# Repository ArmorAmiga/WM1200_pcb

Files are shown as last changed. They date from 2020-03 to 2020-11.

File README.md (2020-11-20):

# ArmorAmiga "Wishmaster" PCB repository

This is an early prototype of ARM-based A1200 turbo board.

PCB design was created in [KiCAD EDA](https://kicad.org/).

It consists of the following parts:
 * Wishmaster carrier board
 * Alinx AC7010/AC7020 Xilinx Zynq development board (available on Aliexpress, for example: https://aliexpress.ru/item/4000585279066.html). Most likely, you will also need a Xilinx JTAG cable to work with it as a developer.

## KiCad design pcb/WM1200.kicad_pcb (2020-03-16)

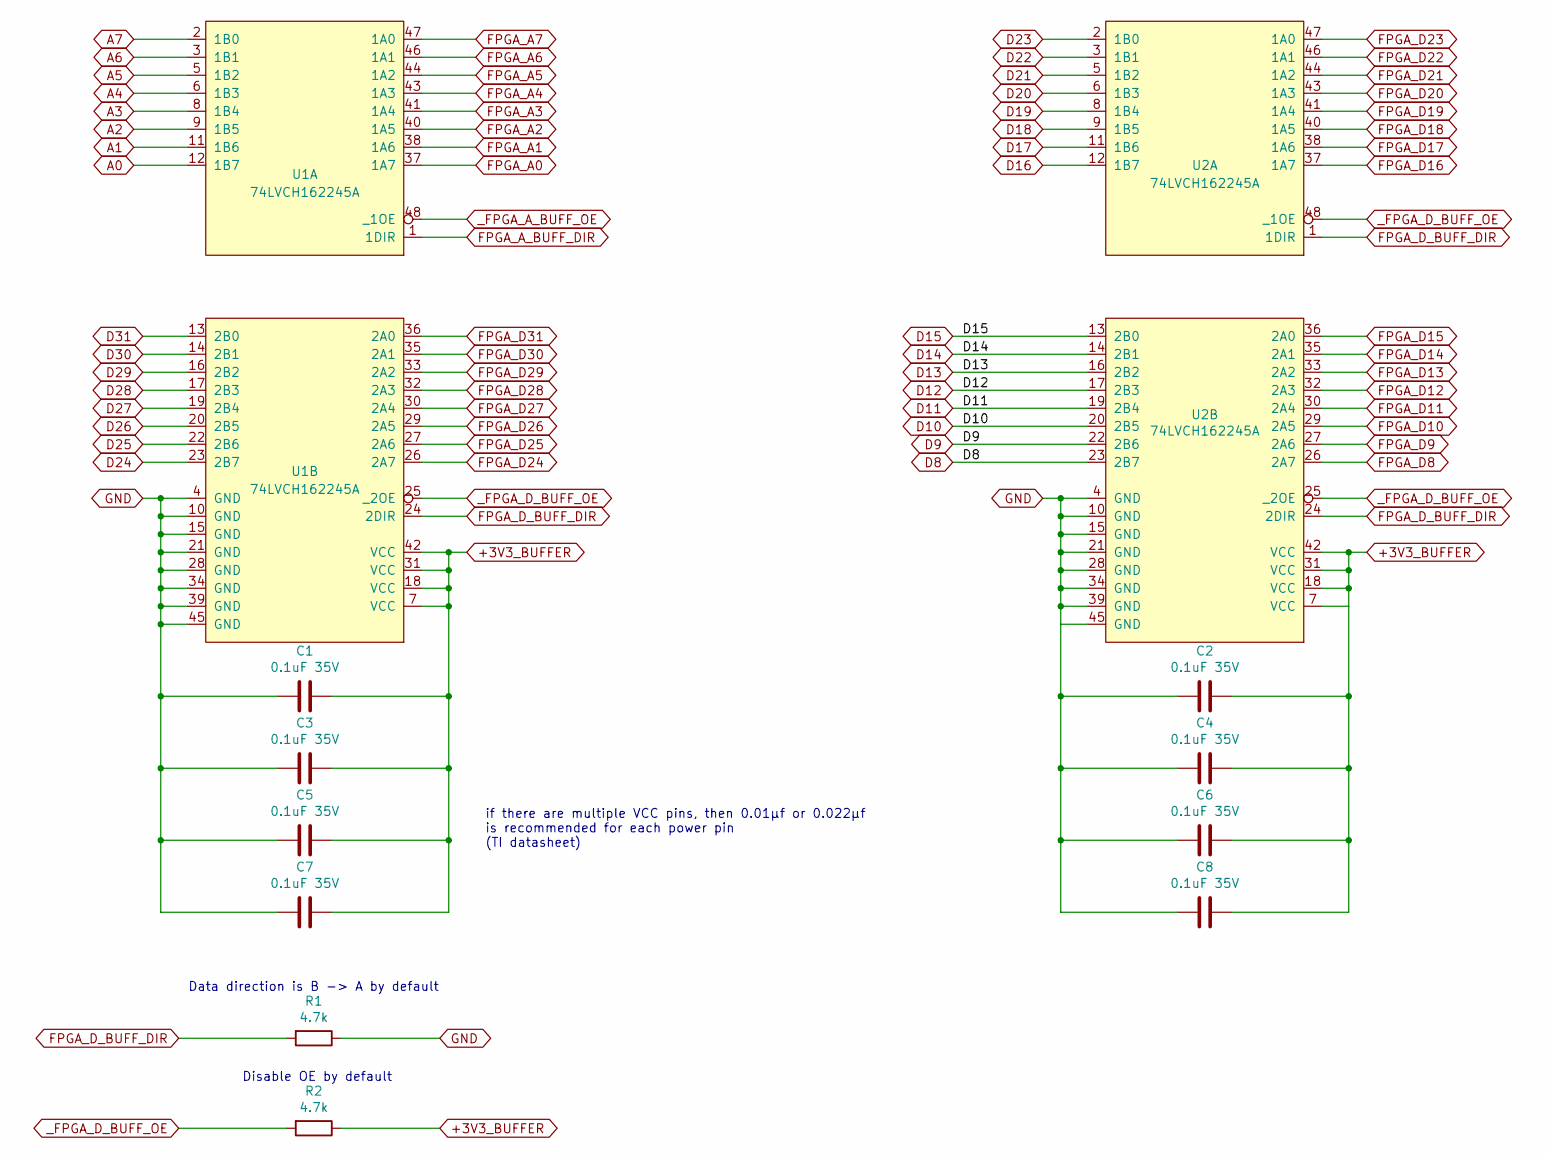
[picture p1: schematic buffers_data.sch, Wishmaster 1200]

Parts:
C1, C2, C3, C4, C5, C6, C7, C8: 0.1uF 35V; C_0402_1005Metric
R1, R2: 4.7k; R_0603_1608Metric_Pad1.05x0.95mm_HandSolder
U1, U2: 74LVCH162245A; TSSOP-48_6.1x12.5mm_P0.5mm

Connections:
+3V3_BUFFER: C1.2, C2.2, C3.2, C4.2, C5.2, C6.2, C7.2, C8.2, R2.1, U1.7 (VCC), U1.18 (VCC), U1.31 (VCC), U1.42 (VCC), U2.7 (VCC), U2.18 (VCC), U2.31 (VCC), U2.42 (VCC); also elsewhere on the board
A0: U1.12 (1B7); also elsewhere on the board
A1: U1.11 (1B6); also elsewhere on the board
A2: U1.9 (1B5); also elsewhere on the board
A3: U1.8 (1B4); also elsewhere on the board
A4: U1.6 (1B3); also elsewhere on the board
A5: U1.5 (1B2); also elsewhere on the board
A6: U1.3 (1B1); also elsewhere on the board
A7: U1.2 (1B0); also elsewhere on the board
D8: U2.23 (2B7); also elsewhere on the board
D9: U2.22 (2B6); also elsewhere on the board
D10: U2.20 (2B5); also elsewhere on the board
D11: U2.19 (2B4); also elsewhere on the board
D12: U2.17 (2B3); also elsewhere on the board
D13: U2.16 (2B2); also elsewhere on the board
D14: U2.14 (2B1); also elsewhere on the board
D15: U2.13 (2B0); also elsewhere on the board
D16: U2.12 (1B7); also elsewhere on the board
D17: U2.11 (1B6); also elsewhere on the board
D18: U2.9 (1B5); also elsewhere on the board
D19: U2.8 (1B4); also elsewhere on the board
D20: U2.6 (1B3); also elsewhere on the board
D21: U2.5 (1B2); also elsewhere on the board
D22: U2.3 (1B1); also elsewhere on the board
D23: U2.2 (1B0); also elsewhere on the board
D24: U1.23 (2B7); also elsewhere on the board
D25: U1.22 (2B6); also elsewhere on the board
D26: U1.20 (2B5); also elsewhere on the board
D27: U1.19 (2B4); also elsewhere on the board
D28: U1.17 (2B3); also elsewhere on the board
D29: U1.16 (2B2); also elsewhere on the board
D30: U1.14 (2B1); also elsewhere on the board
D31: U1.13 (2B0); also elsewhere on the board
FPGA_A0: U1.37 (1A7); also elsewhere on the board
FPGA_A1: U1.38 (1A6); also elsewhere on the board
FPGA_A2: U1.40 (1A5); also elsewhere on the board
FPGA_A3: U1.41 (1A4); also elsewhere on the board
FPGA_A4: U1.43 (1A3); also elsewhere on the board
FPGA_A5: U1.44 (1A2); also elsewhere on the board
FPGA_A6: U1.46 (1A1); also elsewhere on the board
FPGA_A7: U1.47 (1A0); also elsewhere on the board
FPGA_A_BUFF_DIR: U1.1 (1DIR); also elsewhere on the board
FPGA_D8: U2.26 (2A7); also elsewhere on the board
FPGA_D9: U2.27 (2A6); also elsewhere on the board
FPGA_D10: U2.29 (2A5); also elsewhere on the board
FPGA_D11: U2.30 (2A4); also elsewhere on the board
FPGA_D12: U2.32 (2A3); also elsewhere on the board
FPGA_D13: U2.33 (2A2); also elsewhere on the board
FPGA_D14: U2.35 (2A1); also elsewhere on the board
FPGA_D15: U2.36 (2A0); also elsewhere on the board
FPGA_D16: U2.37 (1A7); also elsewhere on the board
FPGA_D17: U2.38 (1A6); also elsewhere on the board
FPGA_D18: U2.40 (1A5); also elsewhere on the board
FPGA_D19: U2.41 (1A4); also elsewhere on the board
FPGA_D20: U2.43 (1A3); also elsewhere on the board
FPGA_D21: U2.44 (1A2); also elsewhere on the board
FPGA_D22: U2.46 (1A1); also elsewhere on the board
FPGA_D23: U2.47 (1A0); also elsewhere on the board
FPGA_D24: U1.26 (2A7); also elsewhere on the board
FPGA_D25: U1.27 (2A6); also elsewhere on the board
FPGA_D26: U1.29 (2A5); also elsewhere on the board
FPGA_D27: U1.30 (2A4); also elsewhere on the board
FPGA_D28: U1.32 (2A3); also elsewhere on the board
FPGA_D29: U1.33 (2A2); also elsewhere on the board
FPGA_D30: U1.35 (2A1); also elsewhere on the board
FPGA_D31: U1.36 (2A0); also elsewhere on the board
FPGA_D_BUFF_DIR: R1.2, U1.24 (2DIR), U2.1 (1DIR), U2.24 (2DIR); also elsewhere on the board
GND: C1.1, C2.1, C3.1, C4.1, C5.1, C6.1, C7.1, C8.1, R1.1, U1.4 (GND), U1.10 (GND), U1.15 (GND), U1.21 (GND), U1.28 (GND), U1.34 (GND), U1.39 (GND), U1.45 (GND), U2.4 (GND), U2.10 (GND), U2.15 (GND), U2.21 (GND), U2.28 (GND), U2.34 (GND), U2.39 (GND), U2.45 (GND); also elsewhere on the board
_FPGA_A_BUFF_OE: U1.48 (_1OE); also elsewhere on the board
_FPGA_D_BUFF_OE: R2.2, U1.25 (_2OE), U2.25 (_2OE), U2.48 (_1OE); also elsewhere on the board

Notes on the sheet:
Disable OE by default
Data direction is B -> A by default
if there are multiple VCC pins, then 0.01μf or 0.022μf is recommended for each power pin (TI datasheet)

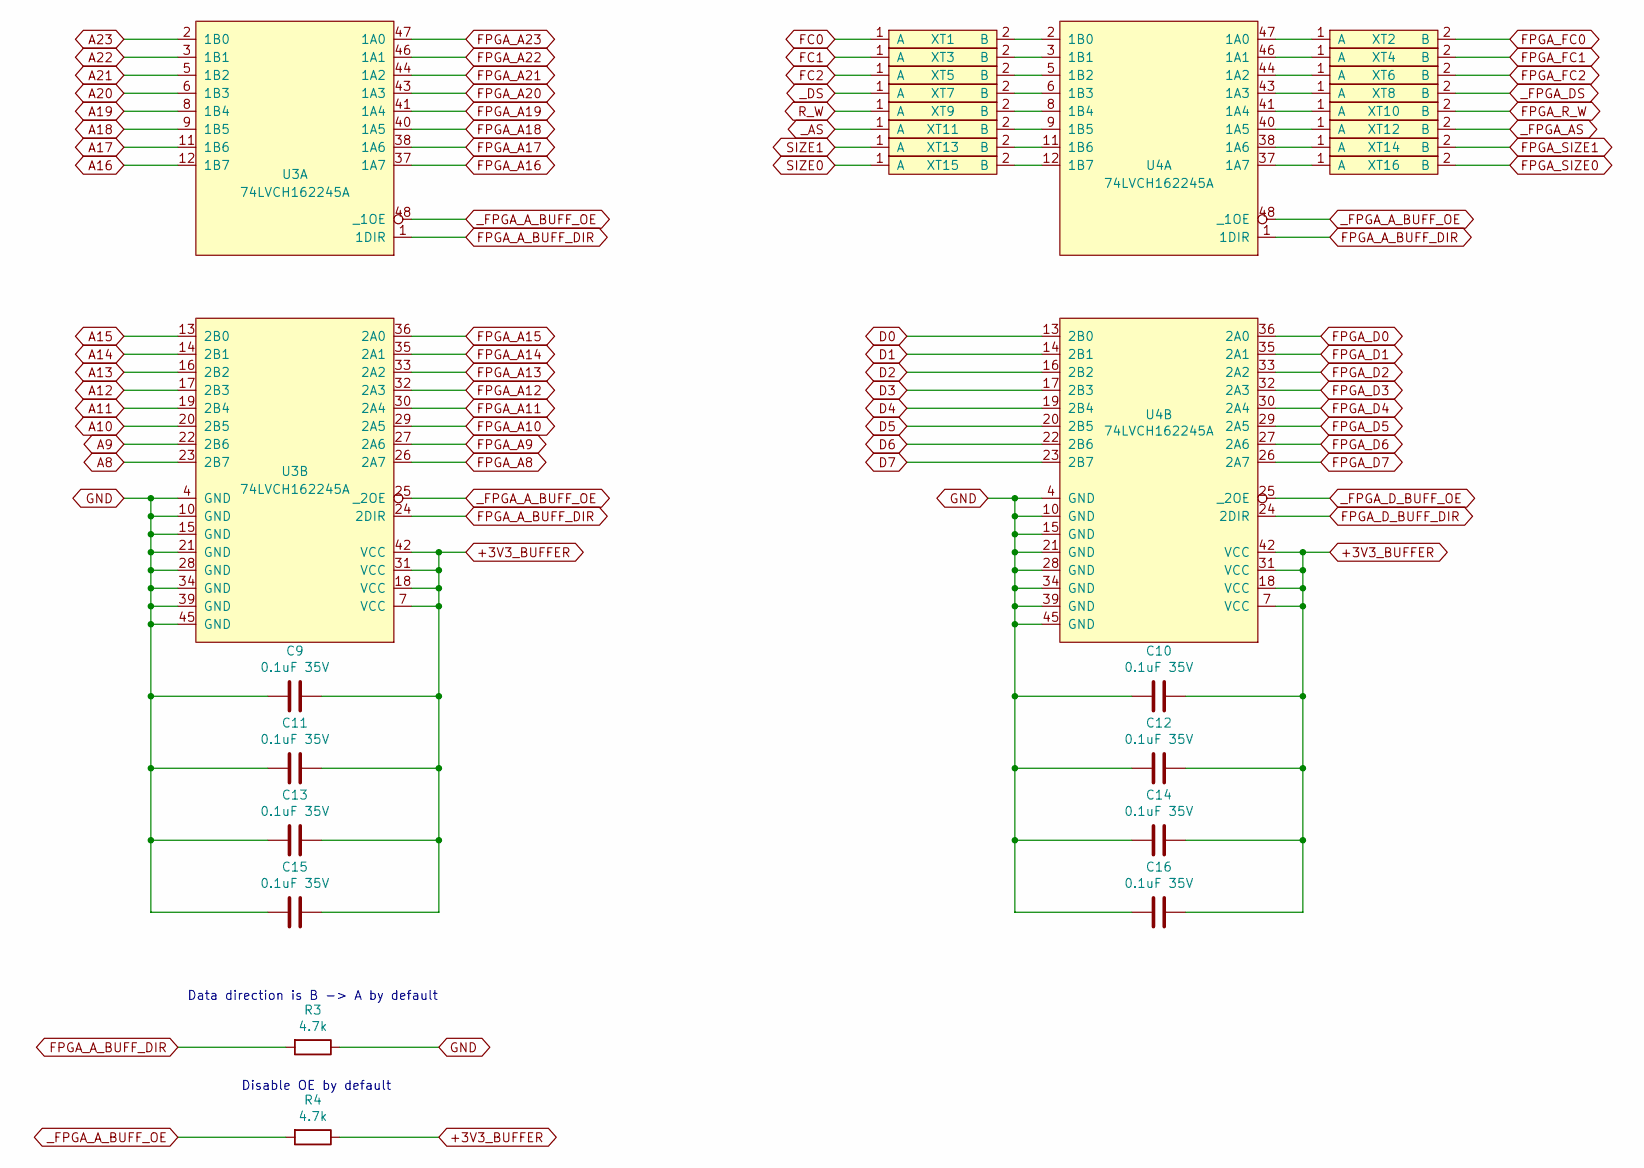
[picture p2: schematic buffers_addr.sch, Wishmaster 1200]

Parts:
C9, C10, C11, C12, C13, C14, C15, C16: 0.1uF 35V; C_0402_1005Metric
R3, R4: 4.7k; R_0603_1608Metric_Pad1.05x0.95mm_HandSolder
U3, U4: 74LVCH162245A; TSSOP-48_6.1x12.5mm_P0.5mm
XT1, XT2, XT3, XT4, XT5, XT6, XT7, XT8, XT9, XT10, XT11, XT12, XT13, XT14, XT15, XT16: testpoint_cutline

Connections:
+3V3_BUFFER: C9.2, C10.2, C11.2, C12.2, C13.2, C14.2, C15.2, C16.2, R4.1, U3.7 (VCC), U3.18 (VCC), U3.31 (VCC), U3.42 (VCC), U4.7 (VCC), U4.18 (VCC), U4.31 (VCC), U4.42 (VCC); also elsewhere on the board
A8: U3.23 (2B7); also elsewhere on the board
A9: U3.22 (2B6); also elsewhere on the board
A10: U3.20 (2B5); also elsewhere on the board
A11: U3.19 (2B4); also elsewhere on the board
A12: U3.17 (2B3); also elsewhere on the board
A13: U3.16 (2B2); also elsewhere on the board
A14: U3.14 (2B1); also elsewhere on the board
A15: U3.13 (2B0); also elsewhere on the board
A16: U3.12 (1B7); also elsewhere on the board
A17: U3.11 (1B6); also elsewhere on the board
A18: U3.9 (1B5); also elsewhere on the board
A19: U3.8 (1B4); also elsewhere on the board
A20: U3.6 (1B3); also elsewhere on the board
A21: U3.5 (1B2); also elsewhere on the board
A22: U3.3 (1B1); also elsewhere on the board
A23: U3.2 (1B0); also elsewhere on the board
D0: U4.13 (2B0); also elsewhere on the board
D1: U4.14 (2B1); also elsewhere on the board
D2: U4.16 (2B2); also elsewhere on the board
D3: U4.17 (2B3); also elsewhere on the board
D4: U4.19 (2B4); also elsewhere on the board
D5: U4.20 (2B5); also elsewhere on the board
D6: U4.22 (2B6); also elsewhere on the board
D7: U4.23 (2B7); also elsewhere on the board
FC0: XT1.1 (A); also elsewhere on the board
FC1: XT3.1 (A); also elsewhere on the board
FC2: XT5.1 (A); also elsewhere on the board
FPGA_A8: U3.26 (2A7); also elsewhere on the board
FPGA_A9: U3.27 (2A6); also elsewhere on the board
FPGA_A10: U3.29 (2A5); also elsewhere on the board
FPGA_A11: U3.30 (2A4); also elsewhere on the board
FPGA_A12: U3.32 (2A3); also elsewhere on the board
FPGA_A13: U3.33 (2A2); also elsewhere on the board
FPGA_A14: U3.35 (2A1); also elsewhere on the board
FPGA_A15: U3.36 (2A0); also elsewhere on the board
FPGA_A16: U3.37 (1A7); also elsewhere on the board
FPGA_A17: U3.38 (1A6); also elsewhere on the board
FPGA_A18: U3.40 (1A5); also elsewhere on the board
FPGA_A19: U3.41 (1A4); also elsewhere on the board
FPGA_A20: U3.43 (1A3); also elsewhere on the board
FPGA_A21: U3.44 (1A2); also elsewhere on the board
FPGA_A22: U3.46 (1A1); also elsewhere on the board
FPGA_A23: U3.47 (1A0); also elsewhere on the board
FPGA_A_BUFF_DIR: R3.2, U3.1 (1DIR), U3.24 (2DIR), U4.1 (1DIR); also elsewhere on the board
FPGA_D0: U4.36 (2A0); also elsewhere on the board
FPGA_D1: U4.35 (2A1); also elsewhere on the board
FPGA_D2: U4.33 (2A2); also elsewhere on the board
FPGA_D3: U4.32 (2A3); also elsewhere on the board
FPGA_D4: U4.30 (2A4); also elsewhere on the board
FPGA_D5: U4.29 (2A5); also elsewhere on the board
FPGA_D6: U4.27 (2A6); also elsewhere on the board
FPGA_D7: U4.26 (2A7); also elsewhere on the board
FPGA_D_BUFF_DIR: U4.24 (2DIR); also elsewhere on the board
FPGA_FC0: XT2.2 (B); also elsewhere on the board
FPGA_FC1: XT4.2 (B); also elsewhere on the board
FPGA_FC2: XT6.2 (B); also elsewhere on the board
FPGA_R_W: XT10.2 (B); also elsewhere on the board
FPGA_SIZE0: XT16.2 (B); also elsewhere on the board
FPGA_SIZE1: XT14.2 (B); also elsewhere on the board
GND: C9.1, C10.1, C11.1, C12.1, C13.1, C14.1, C15.1, C16.1, R3.1, U3.4 (GND), U3.10 (GND), U3.15 (GND), U3.21 (GND), U3.28 (GND), U3.34 (GND), U3.39 (GND), U3.45 (GND), U4.4 (GND), U4.10 (GND), U4.15 (GND), U4.21 (GND), U4.28 (GND), U4.34 (GND), U4.39 (GND), U4.45 (GND); also elsewhere on the board
unnamed: U4.2 (1B0), XT1.2 (B)
unnamed: U4.3 (1B1), XT3.2 (B)
unnamed: U4.5 (1B2), XT5.2 (B)
unnamed: U4.6 (1B3), XT7.2 (B)
unnamed: U4.8 (1B4), XT9.2 (B)
unnamed: U4.9 (1B5), XT11.2 (B)
unnamed: U4.11 (1B6), XT13.2 (B)
unnamed: U4.12 (1B7), XT15.2 (B)
unnamed: U4.37 (1A7), XT16.1 (A)
unnamed: U4.38 (1A6), XT14.1 (A)
unnamed: U4.40 (1A5), XT12.1 (A)
unnamed: U4.41 (1A4), XT10.1 (A)
unnamed: U4.43 (1A3), XT8.1 (A)
unnamed: U4.44 (1A2), XT6.1 (A)
unnamed: U4.46 (1A1), XT4.1 (A)
unnamed: U4.47 (1A0), XT2.1 (A)
R_W: XT9.1 (A); also elsewhere on the board
SIZE0: XT15.1 (A); also elsewhere on the board
SIZE1: XT13.1 (A); also elsewhere on the board
_AS: XT11.1 (A); also elsewhere on the board
_DS: XT7.1 (A); also elsewhere on the board
_FPGA_AS: XT12.2 (B); also elsewhere on the board
_FPGA_A_BUFF_OE: R4.2, U3.25 (_2OE), U3.48 (_1OE), U4.48 (_1OE); also elsewhere on the board
_FPGA_DS: XT8.2 (B); also elsewhere on the board
_FPGA_D_BUFF_OE: U4.25 (_2OE); also elsewhere on the board

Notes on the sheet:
Disable OE by default
Data direction is B -> A by default

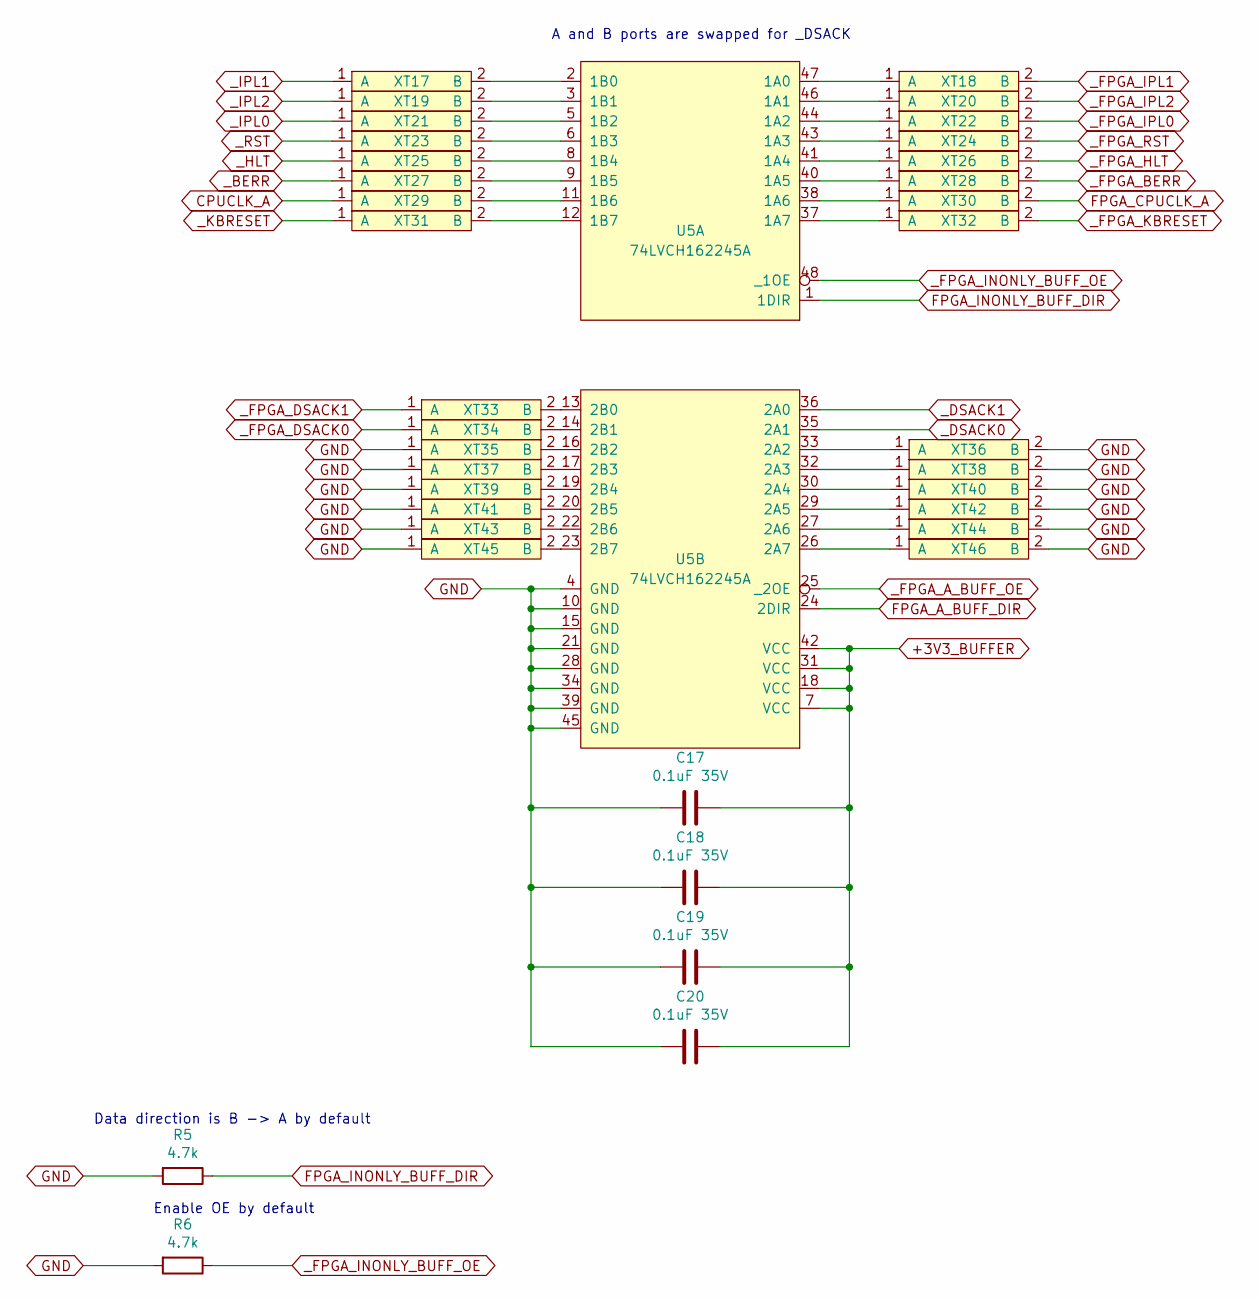
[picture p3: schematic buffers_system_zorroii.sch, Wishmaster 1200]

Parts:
C17, C18, C19, C20: 0.1uF 35V; C_0402_1005Metric
R5, R6: 4.7k; R_0603_1608Metric_Pad1.05x0.95mm_HandSolder
U5: 74LVCH162245A; TSSOP-48_6.1x12.5mm_P0.5mm
XT17, XT18, XT19, XT20, XT21, XT22, XT23, XT24, XT25, XT26, XT27, XT28, XT29, XT30, XT31, XT32, XT33, XT34, XT35, XT36, XT37, XT38, XT39, XT40, XT41, XT42, XT43, XT44, XT45, XT46: testpoint_cutline

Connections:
+3V3_BUFFER: C17.2, C18.2, C19.2, C20.2, U5.7 (VCC), U5.18 (VCC), U5.31 (VCC), U5.42 (VCC); also elsewhere on the board
CPUCLK_A: XT29.1 (A); also elsewhere on the board
FPGA_A_BUFF_DIR: U5.24 (2DIR); also elsewhere on the board
FPGA_CPUCLK_A: XT30.2 (B); also elsewhere on the board
FPGA_INONLY_BUFF_DIR: R5.1, U5.1 (1DIR)
GND: C17.1, C18.1, C19.1, C20.1, R5.2, R6.2, U5.4 (GND), U5.10 (GND), U5.15 (GND), U5.21 (GND), U5.28 (GND), U5.34 (GND), U5.39 (GND), U5.45 (GND), XT35.1 (A), XT36.2 (B), XT37.1 (A), XT38.2 (B), XT39.1 (A), XT40.2 (B), XT41.1 (A), XT42.2 (B), XT43.1 (A), XT44.2 (B), XT45.1 (A), XT46.2 (B); also elsewhere on the board
unnamed: U5.2 (1B0), XT17.2 (B)
unnamed: U5.3 (1B1), XT19.2 (B)
unnamed: U5.5 (1B2), XT21.2 (B)
unnamed: U5.6 (1B3), XT23.2 (B)
unnamed: U5.8 (1B4), XT25.2 (B)
unnamed: U5.9 (1B5), XT27.2 (B)
unnamed: U5.11 (1B6), XT29.2 (B)
unnamed: U5.12 (1B7), XT31.2 (B)
unnamed: U5.13 (2B0), XT33.2 (B)
unnamed: U5.14 (2B1), XT34.2 (B)
unnamed: U5.16 (2B2), XT35.2 (B)
unnamed: U5.17 (2B3), XT37.2 (B)
unnamed: U5.19 (2B4), XT39.2 (B)
unnamed: U5.20 (2B5), XT41.2 (B)
unnamed: U5.22 (2B6), XT43.2 (B)
unnamed: U5.23 (2B7), XT45.2 (B)
unnamed: U5.26 (2A7), XT46.1 (A)
unnamed: U5.27 (2A6), XT44.1 (A)
unnamed: U5.29 (2A5), XT42.1 (A)
unnamed: U5.30 (2A4), XT40.1 (A)
unnamed: U5.32 (2A3), XT38.1 (A)
unnamed: U5.33 (2A2), XT36.1 (A)
unnamed: U5.37 (1A7), XT32.1 (A)
unnamed: U5.38 (1A6), XT30.1 (A)
unnamed: U5.40 (1A5), XT28.1 (A)
unnamed: U5.41 (1A4), XT26.1 (A)
unnamed: U5.43 (1A3), XT24.1 (A)
unnamed: U5.44 (1A2), XT22.1 (A)
unnamed: U5.46 (1A1), XT20.1 (A)
unnamed: U5.47 (1A0), XT18.1 (A)
_BERR: XT27.1 (A); also elsewhere on the board
_DSACK0: U5.35 (2A1); also elsewhere on the board
_DSACK1: U5.36 (2A0); also elsewhere on the board
_FPGA_A_BUFF_OE: U5.25 (_2OE); also elsewhere on the board
_FPGA_BERR: XT28.2 (B); also elsewhere on the board
_FPGA_DSACK0: XT34.1 (A); also elsewhere on the board
_FPGA_DSACK1: XT33.1 (A); also elsewhere on the board
_FPGA_HLT: XT26.2 (B); also elsewhere on the board
_FPGA_INONLY_BUFF_OE: R6.1, U5.48 (_1OE)
_FPGA_IPL0: XT22.2 (B); also elsewhere on the board
_FPGA_IPL1: XT18.2 (B); also elsewhere on the board
_FPGA_IPL2: XT20.2 (B); also elsewhere on the board
_FPGA_KBRESET: XT32.2 (B); also elsewhere on the board
_FPGA_RST: XT24.2 (B); also elsewhere on the board
_HLT: XT25.1 (A); also elsewhere on the board
_IPL0: XT21.1 (A); also elsewhere on the board
_IPL1: XT17.1 (A); also elsewhere on the board
_IPL2: XT19.1 (A); also elsewhere on the board
_KBRESET: XT31.1 (A); also elsewhere on the board
_RST: XT23.1 (A); also elsewhere on the board

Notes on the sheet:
Enable OE by default
Data direction is B -> A by default
A and B ports are swapped for _DSACK

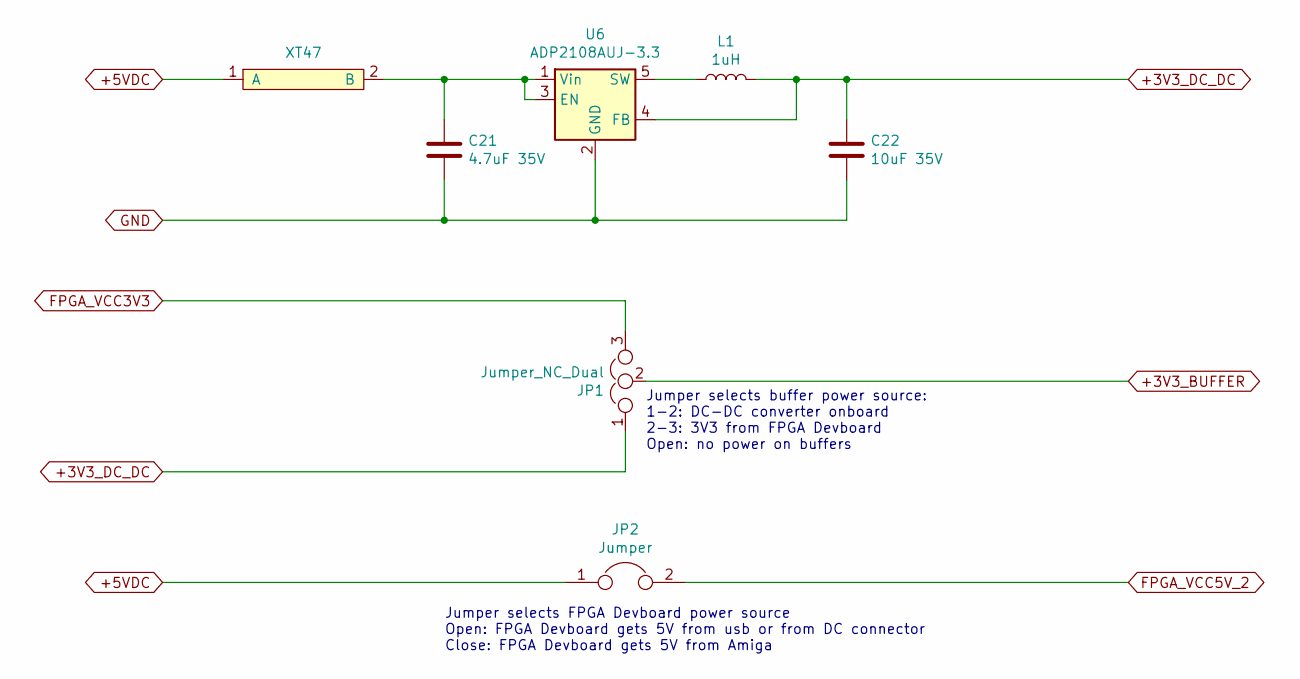
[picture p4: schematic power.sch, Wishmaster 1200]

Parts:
C21: 4.7uF 35V; C_1210_3225Metric_Pad1.42x2.65mm_HandSolder
C22: 10uF 35V; C_1210_3225Metric_Pad1.42x2.65mm_HandSolder
JP1: Jumper_NC_Dual; PinHeader_1x03_P2.54mm_Vertical
JP2: Jumper; PinHeader_1x02_P2.54mm_Vertical
L1: 1uH; L_0603_1608Metric_Pad1.05x0.95mm_HandSolder
U6: ADP2108AUJ-3.3; TSOT-23-5
XT47: testpoint_cutline; testpoint_cutline_fat

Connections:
+3V3_BUFFER: JP1.2; also elsewhere on the board
+3V3_DC_DC: C22.1, JP1.1, L1.2, U6.4 (FB)
+5VDC: JP2.1, XT47.1 (A); also elsewhere on the board
FPGA_VCC3V3: JP1.3; also elsewhere on the board
FPGA_VCC5V_2: JP2.2; also elsewhere on the board
GND: C21.2, C22.2, U6.2 (GND); also elsewhere on the board
unnamed: C21.1, U6.1 (Vin), U6.3 (EN), XT47.2 (B)
unnamed: L1.1, U6.5 (SW)

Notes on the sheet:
Jumper selects buffer power source: 1-2: DC-DC converter onboard 2-3: 3V3 from FPGA Devboard Open: no power on buffers
Jumper selects FPGA Devboard power source Open: FPGA Devboard gets 5V from usb or from DC connector Close: FPGA Devboard gets 5V from Amiga

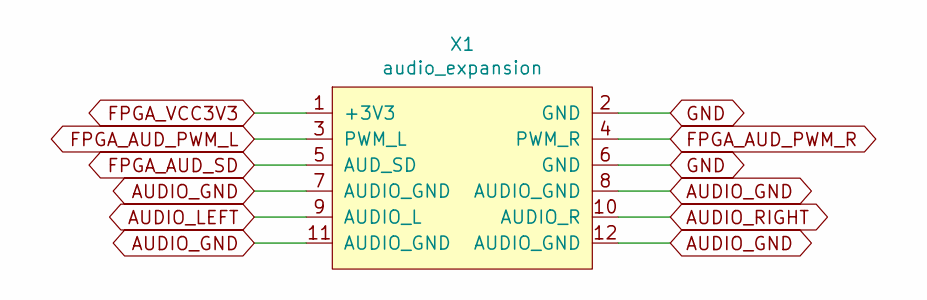
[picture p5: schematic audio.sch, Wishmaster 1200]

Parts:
X1: audio_expansion; PinHeader_2x06_P2.54mm_Vertical

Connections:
AUDIO_GND: X1.7 (AUDIO_GND), X1.8 (AUDIO_GND), X1.11 (AUDIO_GND), X1.12 (AUDIO_GND); also elsewhere on the board
AUDIO_LEFT: X1.9 (AUDIO_L); also elsewhere on the board
AUDIO_RIGHT: X1.10 (AUDIO_R); also elsewhere on the board
FPGA_AUD_PWM_L: X1.3 (PWM_L); also elsewhere on the board
FPGA_AUD_PWM_R: X1.4 (PWM_R); also elsewhere on the board
FPGA_AUD_SD: X1.5 (AUD_SD); also elsewhere on the board
FPGA_VCC3V3: X1.1 (+3V3); also elsewhere on the board
GND: X1.2 (GND), X1.6 (GND); also elsewhere on the board

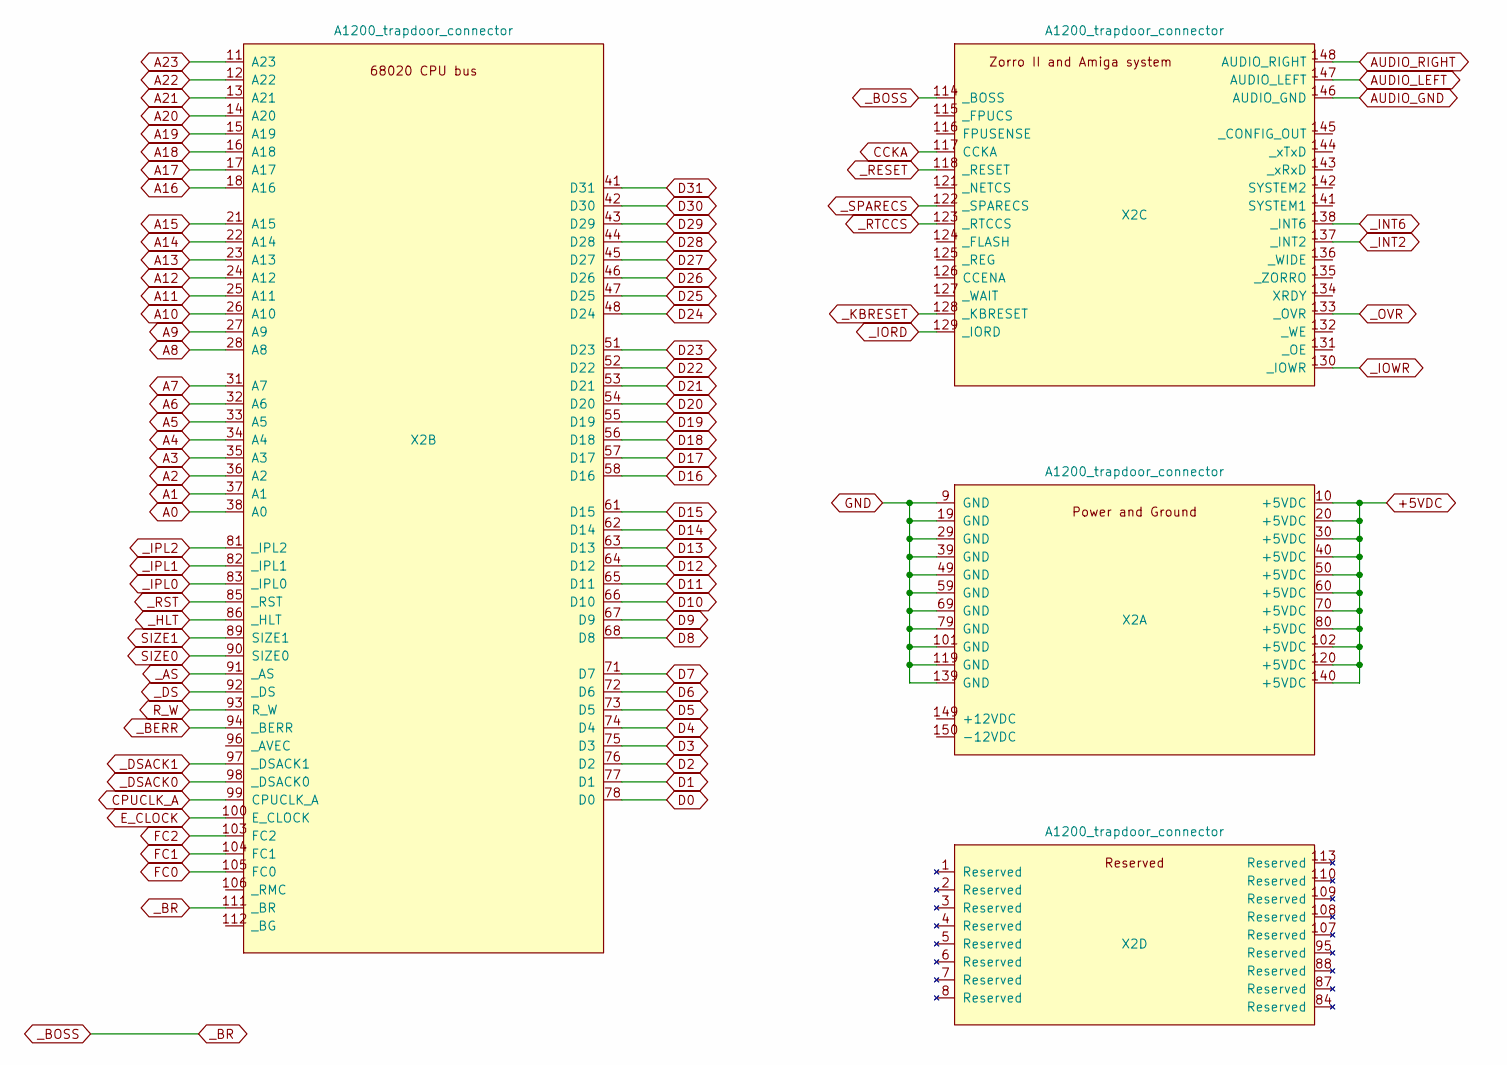
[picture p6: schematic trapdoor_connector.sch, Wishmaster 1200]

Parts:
X2: A1200_trapdoor_connector; Trapdoor_connector

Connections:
+5VDC: X2.10 (+5VDC), X2.20 (+5VDC), X2.30 (+5VDC), X2.40 (+5VDC), X2.50 (+5VDC), X2.60 (+5VDC), X2.70 (+5VDC), X2.80 (+5VDC), X2.102 (+5VDC), X2.120 (+5VDC), X2.140 (+5VDC); also elsewhere on the board
A0: X2.38 (A0); also elsewhere on the board
A1: X2.37 (A1); also elsewhere on the board
A2: X2.36 (A2); also elsewhere on the board
A3: X2.35 (A3); also elsewhere on the board
A4: X2.34 (A4); also elsewhere on the board
A5: X2.33 (A5); also elsewhere on the board
A6: X2.32 (A6); also elsewhere on the board
A7: X2.31 (A7); also elsewhere on the board
A8: X2.28 (A8); also elsewhere on the board
A9: X2.27 (A9); also elsewhere on the board
A10: X2.26 (A10); also elsewhere on the board
A11: X2.25 (A11); also elsewhere on the board
A12: X2.24 (A12); also elsewhere on the board
A13: X2.23 (A13); also elsewhere on the board
A14: X2.22 (A14); also elsewhere on the board
A15: X2.21 (A15); also elsewhere on the board
A16: X2.18 (A16); also elsewhere on the board
A17: X2.17 (A17); also elsewhere on the board
A18: X2.16 (A18); also elsewhere on the board
A19: X2.15 (A19); also elsewhere on the board
A20: X2.14 (A20); also elsewhere on the board
A21: X2.13 (A21); also elsewhere on the board
A22: X2.12 (A22); also elsewhere on the board
A23: X2.11 (A23); also elsewhere on the board
AUDIO_GND: X2.146 (AUDIO_GND); also elsewhere on the board
AUDIO_LEFT: X2.147 (AUDIO_LEFT); also elsewhere on the board
AUDIO_RIGHT: X2.148 (AUDIO_RIGHT); also elsewhere on the board
CCKA: X2.117 (CCKA)
CPUCLK_A: X2.99 (CPUCLK_A); also elsewhere on the board
D0: X2.78 (D0); also elsewhere on the board
D1: X2.77 (D1); also elsewhere on the board
D2: X2.76 (D2); also elsewhere on the board
D3: X2.75 (D3); also elsewhere on the board
D4: X2.74 (D4); also elsewhere on the board
D5: X2.73 (D5); also elsewhere on the board
D6: X2.72 (D6); also elsewhere on the board
D7: X2.71 (D7); also elsewhere on the board
D8: X2.68 (D8); also elsewhere on the board
D9: X2.67 (D9); also elsewhere on the board
D10: X2.66 (D10); also elsewhere on the board
D11: X2.65 (D11); also elsewhere on the board
D12: X2.64 (D12); also elsewhere on the board
D13: X2.63 (D13); also elsewhere on the board
D14: X2.62 (D14); also elsewhere on the board
D15: X2.61 (D15); also elsewhere on the board
D16: X2.58 (D16); also elsewhere on the board
D17: X2.57 (D17); also elsewhere on the board
D18: X2.56 (D18); also elsewhere on the board
D19: X2.55 (D19); also elsewhere on the board
D20: X2.54 (D20); also elsewhere on the board
D21: X2.53 (D21); also elsewhere on the board
D22: X2.52 (D22); also elsewhere on the board
D23: X2.51 (D23); also elsewhere on the board
D24: X2.48 (D24); also elsewhere on the board
D25: X2.47 (D25); also elsewhere on the board
D26: X2.46 (D26); also elsewhere on the board
D27: X2.45 (D27); also elsewhere on the board
D28: X2.44 (D28); also elsewhere on the board
D29: X2.43 (D29); also elsewhere on the board
D30: X2.42 (D30); also elsewhere on the board
D31: X2.41 (D31); also elsewhere on the board
E_CLOCK: X2.100 (E_CLOCK)
FC0: X2.105 (FC0); also elsewhere on the board
FC1: X2.104 (FC1); also elsewhere on the board
FC2: X2.103 (FC2); also elsewhere on the board
GND: X2.9 (GND), X2.19 (GND), X2.29 (GND), X2.39 (GND), X2.49 (GND), X2.59 (GND), X2.69 (GND), X2.79 (GND), X2.101 (GND), X2.119 (GND), X2.139 (GND); also elsewhere on the board
R_W: X2.93 (R_W); also elsewhere on the board
SIZE0: X2.90 (SIZE0); also elsewhere on the board
SIZE1: X2.89 (SIZE1); also elsewhere on the board
_AS: X2.91 (_AS); also elsewhere on the board
_BERR: X2.94 (_BERR); also elsewhere on the board
_BOSS: X2.111 (_BR), X2.114 (_BOSS); also elsewhere on the board
_DS: X2.92 (_DS); also elsewhere on the board
_DSACK0: X2.98 (_DSACK0); also elsewhere on the board
_DSACK1: X2.97 (_DSACK1); also elsewhere on the board
_HLT: X2.86 (_HLT); also elsewhere on the board
_INT2: X2.137 (_INT2); also elsewhere on the board
_INT6: X2.138 (_INT6); also elsewhere on the board
_IORD: X2.129 (_IORD)
_IOWR: X2.130 (_IOWR)
_IPL0: X2.83 (_IPL0); also elsewhere on the board
_IPL1: X2.82 (_IPL1); also elsewhere on the board
_IPL2: X2.81 (_IPL2); also elsewhere on the board
_KBRESET: X2.128 (_KBRESET); also elsewhere on the board
_OVR: X2.133 (_OVR); also elsewhere on the board
_RESET: X2.118 (_RESET)
_RST: X2.85 (_RST); also elsewhere on the board
_RTCCS: X2.123 (_RTCCS)
_SPARECS: X2.122 (_SPARECS)

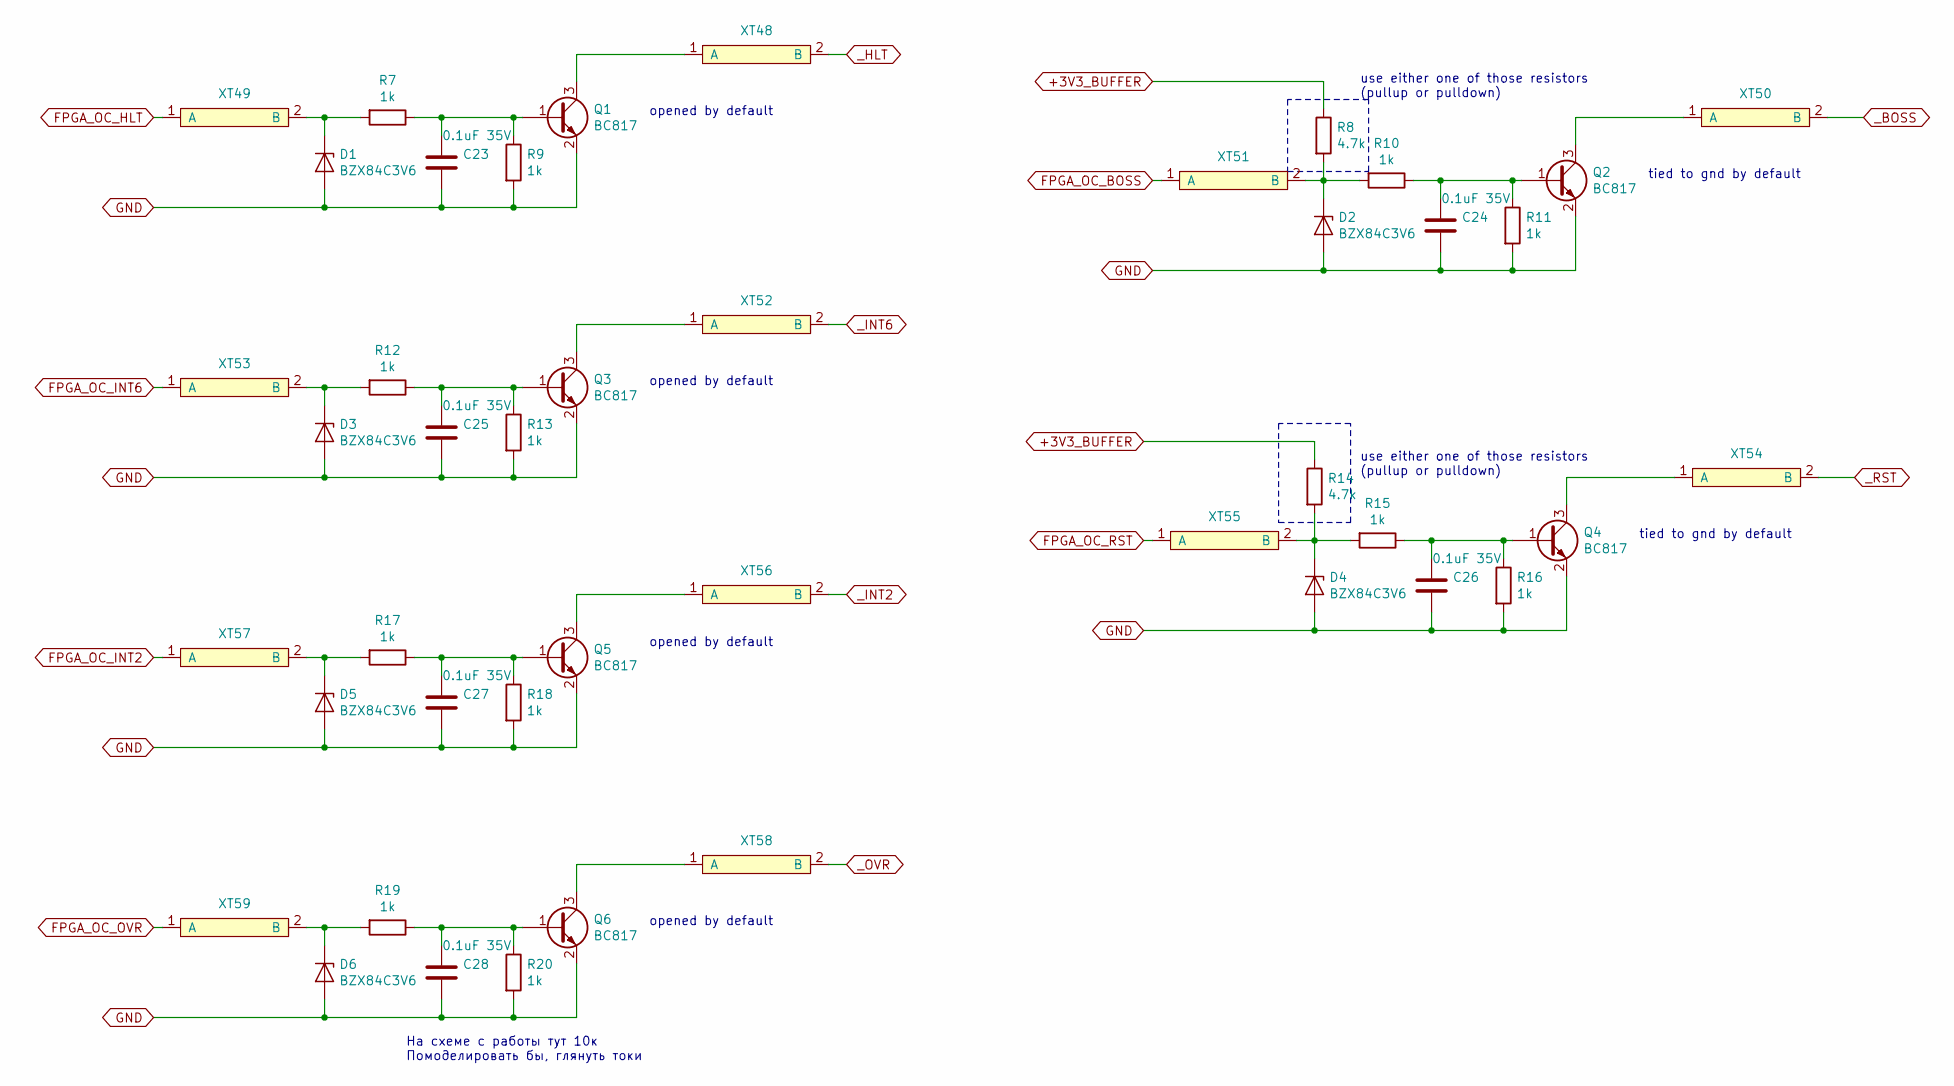
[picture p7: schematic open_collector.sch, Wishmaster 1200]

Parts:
C23, C24, C25, C26, C27, C28: 0.1uF 35V; C_0603_1608Metric_Pad1.05x0.95mm_HandSolder
D1, D2, D3, D4, D5, D6: BZX84C3V6; D_SOT-23_ANK
Q1, Q2, Q3, Q4, Q5, Q6: BC817; SOT-23
R7, R9, R10, R11, R12, R13, R15, R16, R17, R18, R19, R20: 1k; R_0603_1608Metric_Pad1.05x0.95mm_HandSolder
R8, R14: 4.7k; R_0603_1608Metric_Pad1.05x0.95mm_HandSolder
XT48, XT49, XT50, XT51, XT52, XT53, XT54, XT55, XT56, XT57, XT58, XT59: testpoint_cutline

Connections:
+3V3_BUFFER: R8.1, R14.1; also elsewhere on the board
FPGA_OC_BOSS: XT51.1 (A); also elsewhere on the board
FPGA_OC_HLT: XT49.1 (A); also elsewhere on the board
FPGA_OC_INT2: XT57.1 (A); also elsewhere on the board
FPGA_OC_INT6: XT53.1 (A); also elsewhere on the board
FPGA_OC_OVR: XT59.1 (A); also elsewhere on the board
FPGA_OC_RST: XT55.1 (A); also elsewhere on the board
GND: C23.1, C24.1, C25.1, C26.1, C27.1, C28.1, D1.2 (A), D2.2 (A), D3.2 (A), D4.2 (A), D5.2 (A), D6.2 (A), Q1.2 (E), Q2.2 (E), Q3.2 (E), Q4.2 (E), Q5.2 (E), Q6.2 (E), R9.2, R11.2, R13.2, R16.2, R18.2, R20.2; also elsewhere on the board
unnamed: C23.2, Q1.1 (B), R7.1, R9.1
unnamed: C24.2, Q2.1 (B), R10.1, R11.1
unnamed: C25.2, Q3.1 (B), R12.1, R13.1
unnamed: C26.2, Q4.1 (B), R15.1, R16.1
unnamed: C27.2, Q5.1 (B), R17.1, R18.1
unnamed: C28.2, Q6.1 (B), R19.1, R20.1
unnamed: D1.1 (K), R7.2, XT49.2 (B)
unnamed: D2.1 (K), R8.2, R10.2, XT51.2 (B)
unnamed: D3.1 (K), R12.2, XT53.2 (B)
unnamed: D4.1 (K), R14.2, R15.2, XT55.2 (B)
unnamed: D5.1 (K), R17.2, XT57.2 (B)
unnamed: D6.1 (K), R19.2, XT59.2 (B)
unnamed: Q1.3 (C), XT48.1 (A)
unnamed: Q2.3 (C), XT50.1 (A)
unnamed: Q3.3 (C), XT52.1 (A)
unnamed: Q4.3 (C), XT54.1 (A)
unnamed: Q5.3 (C), XT56.1 (A)
unnamed: Q6.3 (C), XT58.1 (A)
_BOSS: XT50.2 (B); also elsewhere on the board
_HLT: XT48.2 (B); also elsewhere on the board
_INT2: XT56.2 (B); also elsewhere on the board
_INT6: XT52.2 (B); also elsewhere on the board
_OVR: XT58.2 (B); also elsewhere on the board
_RST: XT54.2 (B); also elsewhere on the board

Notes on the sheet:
opened by default
tied to gnd by default
use either one of those resistors (pullup or pulldown)
На схеме с работы тут 10к Помоделировать бы, глянуть токи

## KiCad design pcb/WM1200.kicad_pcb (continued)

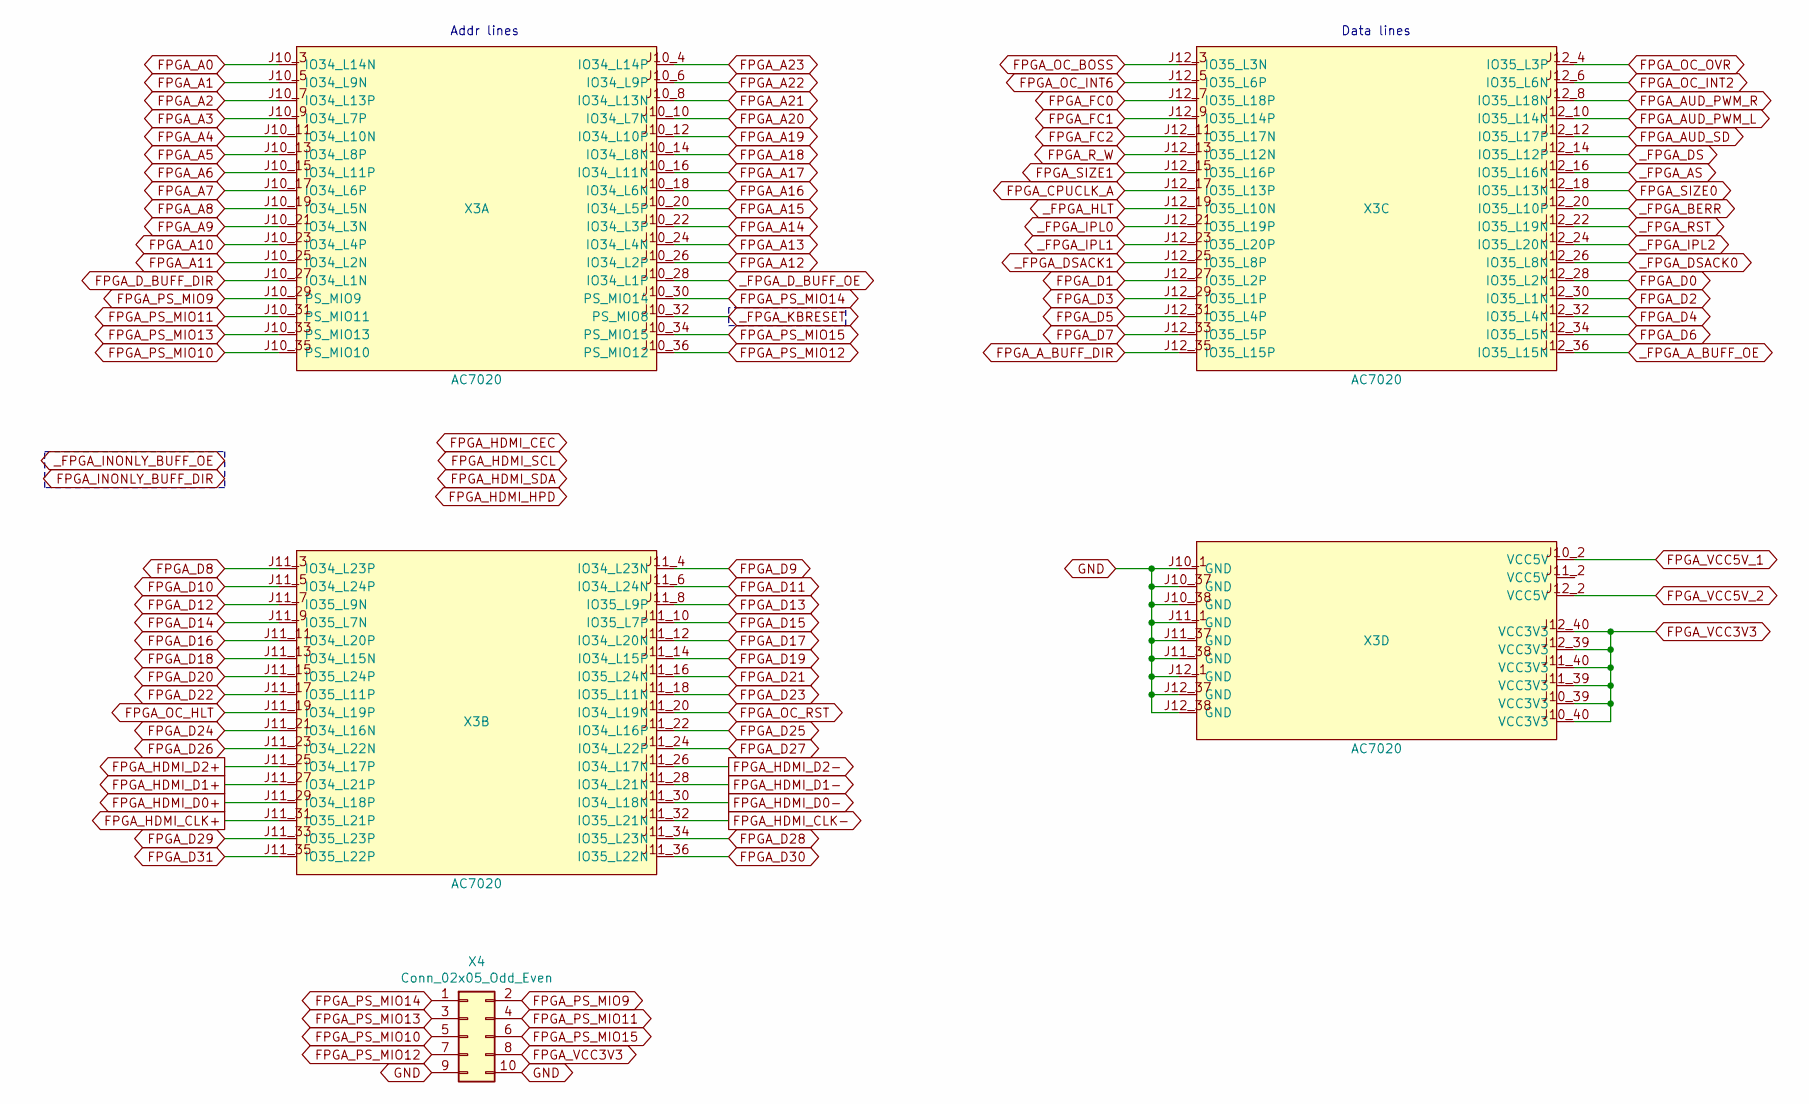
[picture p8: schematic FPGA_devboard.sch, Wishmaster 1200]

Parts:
X3: AC7020; ac7020
X4: Conn_02x05_Odd_Even; PinHeader_2x05_P2.54mm_Vertical

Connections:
FPGA_A0: X3.J10_3 (IO34_L14N); also elsewhere on the board
FPGA_A1: X3.J10_5 (IO34_L9N); also elsewhere on the board
FPGA_A2: X3.J10_7 (IO34_L13P); also elsewhere on the board
FPGA_A3: X3.J10_9 (IO34_L7P); also elsewhere on the board
FPGA_A4: X3.J10_11 (IO34_L10N); also elsewhere on the board
FPGA_A5: X3.J10_13 (IO34_L8P); also elsewhere on the board
FPGA_A6: X3.J10_15 (IO34_L11P); also elsewhere on the board
FPGA_A7: X3.J10_17 (IO34_L6P); also elsewhere on the board
FPGA_A8: X3.J10_19 (IO34_L5N); also elsewhere on the board
FPGA_A9: X3.J10_21 (IO34_L3N); also elsewhere on the board
FPGA_A10: X3.J10_23 (IO34_L4P); also elsewhere on the board
FPGA_A11: X3.J10_25 (IO34_L2N); also elsewhere on the board
FPGA_A12: X3.J10_26 (IO34_L2P); also elsewhere on the board
FPGA_A13: X3.J10_24 (IO34_L4N); also elsewhere on the board
FPGA_A14: X3.J10_22 (IO34_L3P); also elsewhere on the board
FPGA_A15: X3.J10_20 (IO34_L5P); also elsewhere on the board
FPGA_A16: X3.J10_18 (IO34_L6N); also elsewhere on the board
FPGA_A17: X3.J10_16 (IO34_L11N); also elsewhere on the board
FPGA_A18: X3.J10_14 (IO34_L8N); also elsewhere on the board
FPGA_A19: X3.J10_12 (IO34_L10P); also elsewhere on the board
FPGA_A20: X3.J10_10 (IO34_L7N); also elsewhere on the board
FPGA_A21: X3.J10_8 (IO34_L13N); also elsewhere on the board
FPGA_A22: X3.J10_6 (IO34_L9P); also elsewhere on the board
FPGA_A23: X3.J10_4 (IO34_L14P); also elsewhere on the board
FPGA_AUD_PWM_L: X3.J12_10 (IO35_L14N); also elsewhere on the board
FPGA_AUD_PWM_R: X3.J12_8 (IO35_L18N); also elsewhere on the board
FPGA_AUD_SD: X3.J12_12 (IO35_L17P); also elsewhere on the board
FPGA_A_BUFF_DIR: X3.J12_35 (IO35_L15P); also elsewhere on the board
FPGA_CPUCLK_A: X3.J12_17 (IO35_L13P); also elsewhere on the board
FPGA_D0: X3.J12_28 (IO35_L2N); also elsewhere on the board
FPGA_D1: X3.J12_27 (IO35_L2P); also elsewhere on the board
FPGA_D2: X3.J12_30 (IO35_L1N); also elsewhere on the board
FPGA_D3: X3.J12_29 (IO35_L1P); also elsewhere on the board
FPGA_D4: X3.J12_32 (IO35_L4N); also elsewhere on the board
FPGA_D5: X3.J12_31 (IO35_L4P); also elsewhere on the board
FPGA_D6: X3.J12_34 (IO35_L5N); also elsewhere on the board
FPGA_D7: X3.J12_33 (IO35_L5P); also elsewhere on the board
FPGA_D8: X3.J11_3 (IO34_L23P); also elsewhere on the board
FPGA_D9: X3.J11_4 (IO34_L23N); also elsewhere on the board
FPGA_D10: X3.J11_5 (IO34_L24P); also elsewhere on the board
FPGA_D11: X3.J11_6 (IO34_L24N); also elsewhere on the board
FPGA_D12: X3.J11_7 (IO35_L9N); also elsewhere on the board
FPGA_D13: X3.J11_8 (IO35_L9P); also elsewhere on the board
FPGA_D14: X3.J11_9 (IO35_L7N); also elsewhere on the board
FPGA_D15: X3.J11_10 (IO35_L7P); also elsewhere on the board
FPGA_D16: X3.J11_11 (IO34_L20P); also elsewhere on the board
FPGA_D17: X3.J11_12 (IO34_L20N); also elsewhere on the board
FPGA_D18: X3.J11_13 (IO34_L15N); also elsewhere on the board
FPGA_D19: X3.J11_14 (IO34_L15P); also elsewhere on the board
FPGA_D20: X3.J11_15 (IO35_L24P); also elsewhere on the board
FPGA_D21: X3.J11_16 (IO35_L24N); also elsewhere on the board
FPGA_D22: X3.J11_17 (IO35_L11P); also elsewhere on the board
FPGA_D23: X3.J11_18 (IO35_L11N); also elsewhere on the board
FPGA_D24: X3.J11_21 (IO34_L16N); also elsewhere on the board
FPGA_D25: X3.J11_22 (IO34_L16P); also elsewhere on the board
FPGA_D26: X3.J11_23 (IO34_L22N); also elsewhere on the board
FPGA_D27: X3.J11_24 (IO34_L22P); also elsewhere on the board
FPGA_D28: X3.J11_34 (IO35_L23N); also elsewhere on the board
FPGA_D29: X3.J11_33 (IO35_L23P); also elsewhere on the board
FPGA_D30: X3.J11_36 (IO35_L22N); also elsewhere on the board
FPGA_D31: X3.J11_35 (IO35_L22P); also elsewhere on the board
FPGA_D_BUFF_DIR: X3.J10_27 (IO34_L1N); also elsewhere on the board
FPGA_FC0: X3.J12_7 (IO35_L18P); also elsewhere on the board
FPGA_FC1: X3.J12_9 (IO35_L14P); also elsewhere on the board
FPGA_FC2: X3.J12_11 (IO35_L17N); also elsewhere on the board
FPGA_HDMI_CLK+: X3.J11_31 (IO35_L21P); also elsewhere on the board
FPGA_HDMI_CLK-: X3.J11_32 (IO35_L21N); also elsewhere on the board
FPGA_HDMI_D0+: X3.J11_29 (IO34_L18P); also elsewhere on the board
FPGA_HDMI_D0-: X3.J11_30 (IO34_L18N); also elsewhere on the board
FPGA_HDMI_D1+: X3.J11_27 (IO34_L21P); also elsewhere on the board
FPGA_HDMI_D1-: X3.J11_28 (IO34_L21N); also elsewhere on the board
FPGA_HDMI_D2+: X3.J11_25 (IO34_L17P); also elsewhere on the board
FPGA_HDMI_D2-: X3.J11_26 (IO34_L17N); also elsewhere on the board
FPGA_OC_BOSS: X3.J12_3 (IO35_L3N); also elsewhere on the board
FPGA_OC_HLT: X3.J11_19 (IO34_L19P); also elsewhere on the board
FPGA_OC_INT2: X3.J12_6 (IO35_L6N); also elsewhere on the board
FPGA_OC_INT6: X3.J12_5 (IO35_L6P); also elsewhere on the board
FPGA_OC_OVR: X3.J12_4 (IO35_L3P); also elsewhere on the board
FPGA_OC_RST: X3.J11_20 (IO34_L19N); also elsewhere on the board
FPGA_PS_MIO9: X3.J10_29 (PS_MIO9), X4.2
FPGA_PS_MIO10: X3.J10_35 (PS_MIO10), X4.5
FPGA_PS_MIO11: X3.J10_31 (PS_MIO11), X4.4
FPGA_PS_MIO12: X3.J10_36 (PS_MIO12), X4.7
FPGA_PS_MIO13: X3.J10_33 (PS_MIO13), X4.3
FPGA_PS_MIO14: X3.J10_30 (PS_MIO14), X4.1
FPGA_PS_MIO15: X3.J10_34 (PS_MIO15), X4.6
FPGA_R_W: X3.J12_13 (IO35_L12N); also elsewhere on the board
FPGA_SIZE0: X3.J12_18 (IO35_L13N); also elsewhere on the board
FPGA_SIZE1: X3.J12_15 (IO35_L16P); also elsewhere on the board
FPGA_VCC3V3: X3.J10_39 (VCC3V3), X3.J10_40 (VCC3V3), X3.J11_39 (VCC3V3), X3.J11_40 (VCC3V3), X3.J12_39 (VCC3V3), X3.J12_40 (VCC3V3), X4.8; also elsewhere on the board
FPGA_VCC5V_1: X3.J10_2 (VCC5V); also elsewhere on the board
FPGA_VCC5V_2: X3.J12_2 (VCC5V); also elsewhere on the board
GND: X3.J10_1 (GND), X3.J10_37 (GND), X3.J10_38 (GND), X3.J11_1 (GND), X3.J11_37 (GND), X3.J11_38 (GND), X3.J12_1 (GND), X3.J12_37 (GND), X3.J12_38 (GND), X4.9, X4.10; also elsewhere on the board
_FPGA_AS: X3.J12_16 (IO35_L16N); also elsewhere on the board
_FPGA_A_BUFF_OE: X3.J12_36 (IO35_L15N); also elsewhere on the board
_FPGA_BERR: X3.J12_20 (IO35_L10P); also elsewhere on the board
_FPGA_DS: X3.J12_14 (IO35_L12P); also elsewhere on the board
_FPGA_DSACK0: X3.J12_26 (IO35_L8N); also elsewhere on the board
_FPGA_DSACK1: X3.J12_25 (IO35_L8P); also elsewhere on the board
_FPGA_D_BUFF_OE: X3.J10_28 (IO34_L1P); also elsewhere on the board
_FPGA_HLT: X3.J12_19 (IO35_L10N); also elsewhere on the board
_FPGA_IPL0: X3.J12_21 (IO35_L19P); also elsewhere on the board
_FPGA_IPL1: X3.J12_23 (IO35_L20P); also elsewhere on the board
_FPGA_IPL2: X3.J12_24 (IO35_L20N); also elsewhere on the board
_FPGA_KBRESET: X3.J10_32 (PS_MIO8); also elsewhere on the board
_FPGA_RST: X3.J12_22 (IO35_L19N); also elsewhere on the board

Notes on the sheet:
Data lines
Addr lines

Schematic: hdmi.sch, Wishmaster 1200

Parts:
C29, C30, C31: 0.1uF 35V; C_0603_1608Metric_Pad1.05x0.95mm_HandSolder
C32: 1nF 250V; C_0603_1608Metric_Pad1.05x0.95mm_HandSolder
R21, R22, R23, R25: 4.7k; R_0603_1608Metric_Pad1.05x0.95mm_HandSolder
R24: 1M; R_0603_1608Metric_Pad1.05x0.95mm_HandSolder
U7: TPD12S016PWR; TSSOP-24_4.4x7.8mm_P0.65mm
X5: HDMI_A; HDMI-19-02F

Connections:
FPGA_HDMI_CEC: U7.1 (CEC_A)
FPGA_HDMI_CLK+: U7.16 (CLK+), X5.10 (CK+); also elsewhere on the board
FPGA_HDMI_CLK-: U7.15 (CLK-), X5.12 (CK-); also elsewhere on the board
FPGA_HDMI_CT_HPD: R23.1, U7.12 (CT_HPD)
FPGA_HDMI_D0+: U7.18 (D0+), X5.7 (D0+); also elsewhere on the board
FPGA_HDMI_D0-: U7.17 (D0-), X5.9 (D0-); also elsewhere on the board
FPGA_HDMI_D1+: U7.21 (D1+), X5.4 (D1+); also elsewhere on the board
FPGA_HDMI_D1-: U7.20 (D1-), X5.6 (D1-); also elsewhere on the board
FPGA_HDMI_D2+: U7.23 (D2+), X5.1 (D2+); also elsewhere on the board
FPGA_HDMI_D2-: U7.22 (D2-), X5.3 (D2-); also elsewhere on the board
FPGA_HDMI_HPD: U7.4 (HPD_A)
FPGA_HDMI_LS_OE: R25.2, U7.5 (LS_OE)
FPGA_HDMI_SCL: R21.1, U7.2 (SCL_A)
FPGA_HDMI_SDA: R22.2, U7.3 (SDA_A)
FPGA_VCC3V3: C31.1, R21.2, R22.1, R23.2, R25.1, U7.24 (VCCA); also elsewhere on the board
FPGA_VCC5V_1: C30.1, U7.11 (VCC5V); also elsewhere on the board
GND: C29.2, C30.2, C31.2, C32.2, R24.2, U7.6 (GND), U7.14 (GND), U7.19 (GND), X5.2 (D2S), X5.5 (D1S), X5.8 (D0S), X5.11 (CKS), X5.17 (GND); also elsewhere on the board
unnamed: C29.1, U7.13 (5V_OUT), X5.18 (+5V)
unnamed: C32.1, R24.1, X5.SH
unnamed: U7.7 (CEC_B), X5.13 (CEC)
unnamed: U7.8 (SCL_B), X5.15 (SCL)
unnamed: U7.9 (SDA_B), X5.16 (SDA)
unnamed: U7.10 (HPD_B), X5.19 (HPD)

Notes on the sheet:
i2c pullup (not sure if i2c will be used here) tpd12s016 seems to have it's own pullups -- not needed?
enable pullups for tpd12s016

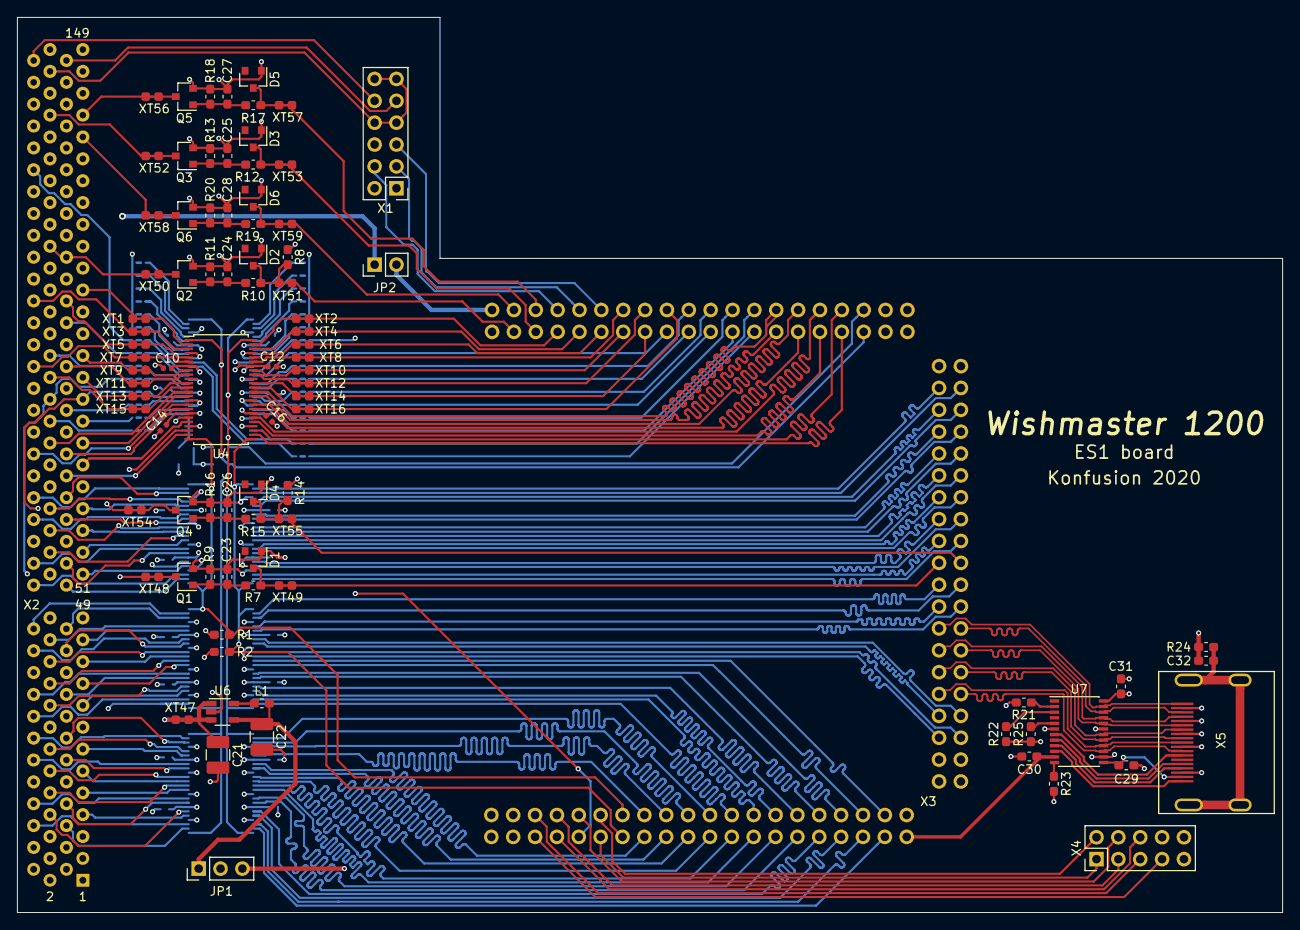
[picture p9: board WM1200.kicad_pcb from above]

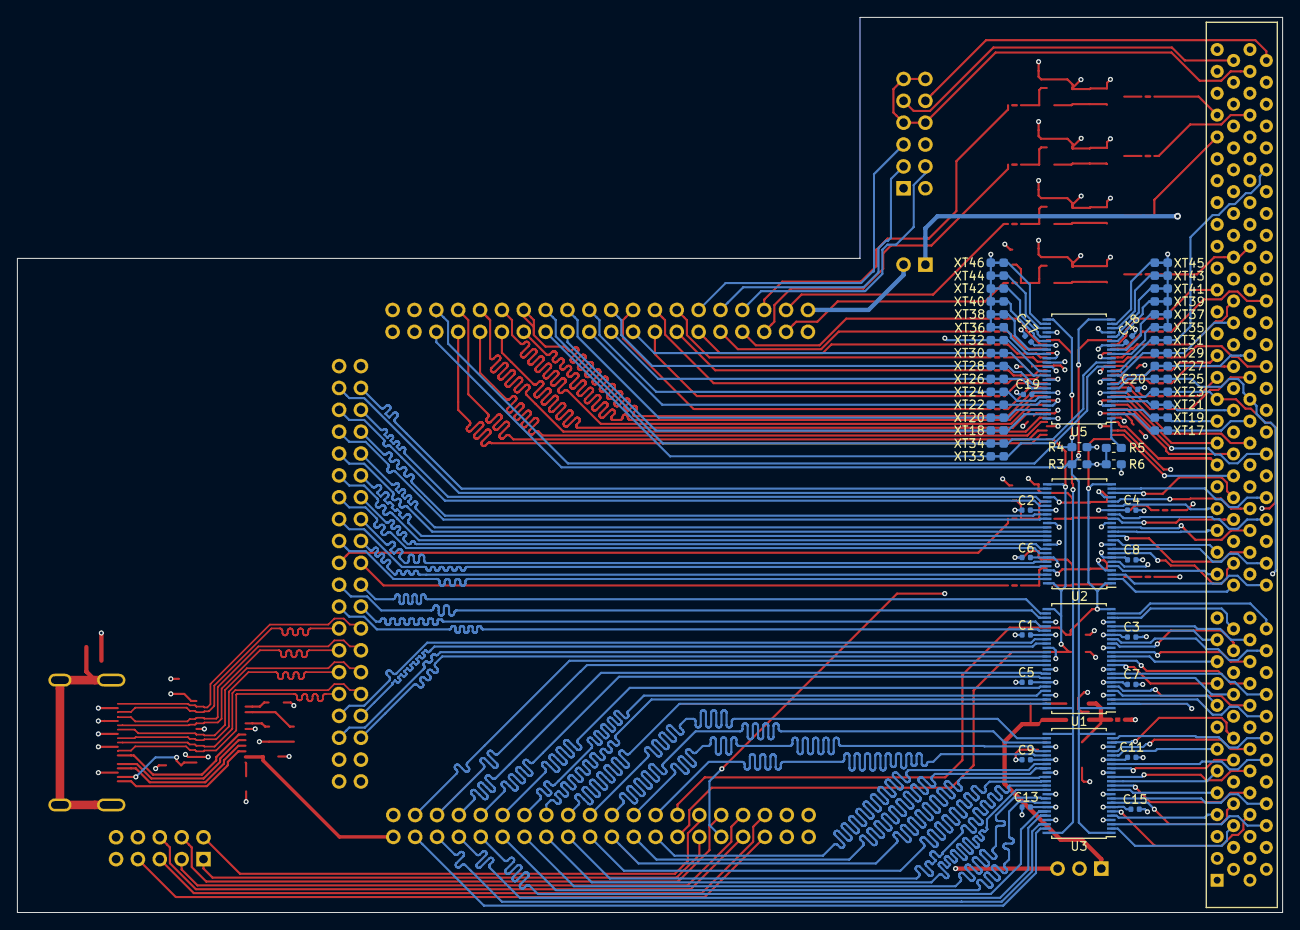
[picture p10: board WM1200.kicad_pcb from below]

Board: 4 copper layers, 147.0 x 104.0 mm, 143 parts (54 on the bottom side), 268 nets.

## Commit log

2020-02-24 ok, here we go
    [WM1200.kicad_pcb, WM1200.sch, trapdoor_connector.sch]
2020-02-25 hierarchy updated
    [FPGA_devboard.sch, WM1200.sch, audio.sch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]
2020-02-25 new sch lists
    [FPGA_devboard.sch, WM1200.sch, audio.sch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]
2020-02-25 Revert "new sch lists"
    This reverts commit 63e92f37236e6046a75a91c77abd2eec0f4ea4c7.
    [FPGA_devboard.sch, WM1200.sch, audio.sch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]
2020-02-25 some work on sheets
    [WM1200.sch, audio.sch, buffers_1.sch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]
2020-02-25 new list added for power converters
    [WM1200.sch, audio.sch, buffers_addr.sch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]
2020-02-25 hiererchy update
    [FPGA_devboard.sch, WM1200.sch, clockport.sch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]
2020-02-25 buffer section finished, audio moved to expansion connector
    [audio.sch, buffers_addr.sch, buffers_data.sch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]
2020-02-25 some work done on "open collector" list
    [FPGA_devboard.sch, audio.sch, buffers_addr.sch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]
2020-02-25 cosmetical changes in buffers sch's
    [buffers_addr.sch, buffers_data.sch, buffers_system_zorroii.sch]
2020-02-25 AC7020 schlib and sch list updated
    [FPGA_devboard.sch]
2020-02-26 scheme update
    [WM1200.sch, audio.sch, clockport.sch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]
2020-02-26 FPGA side labels added
    [buffers_addr.sch, buffers_data.sch, buffers_system_zorroii.sch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]
2020-02-26 bus name typo fixed on audio sheet
    [WM1200.sch, audio.sch]
2020-02-26 Some work done on the whole project
    [FPGA_devboard.sch, WM1200.sch, audio.sch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]
2020-02-26 The scheme needs it's buses to be remade because of the way KiCad works, ok
    [WM1200.sch, clockport.sch, trapdoor_connector.sch]
2020-02-26 wip commit (sync work between pc's)
    [WM1200.sch, trapdoor_connector.sch]
2020-02-28 ok, we are using global labels now
    [FPGA_devboard.sch, WM1200.sch, audio.sch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]
2020-02-28 fpga-side gpio connector added
    [FPGA_devboard.sch, audio.sch, buffers_addr.sch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]
2020-02-28 Some more changes wip
    [FPGA_devboard.sch, buffers_addr.sch, buffers_data.sch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]
2020-02-29 hdmi list added
    [FPGA_devboard.sch, WM1200.sch, audio.sch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]
2020-02-29 yet another wip commit
    [FPGA_devboard.sch, hdmi.sch]
2020-03-01 open collector list finished
    [open_collector.sch]
2020-03-01 pinout changes
    [FPGA_devboard.sch, hdmi.sch]
2020-03-01 started to design pcb and footprints
    [WM1200.kicad_pcb]
2020-03-01 changed pullup resistance and zener diodes voltage at OC list
    [open_collector.sch]
2020-03-02 testpoints footprints added, some footprints assigned
    [buffers_addr.sch, buffers_data.sch, buffers_system_zorroii.sch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]
2020-03-02 more footprints assigned
    [FPGA_devboard.sch, audio.sch, buffers_addr.sch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]
2020-03-02 more footprints assigned, caps added into open collector base circuit
    [buffers_addr.sch, buffers_data.sch, buffers_system_zorroii.sch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]
2020-03-02 hdmi footprint added, ac7020 footprint added, but not finished yet
2020-03-02 ac7020 footprint finished
2020-03-02 working on pcb
    [FPGA_devboard.sch, WM1200.kicad_pcb, hdmi.sch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]
2020-03-03 working on pcb 2
    [WM1200.kicad_pcb, buffers_addr.sch, buffers_data.sch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]
2020-03-03 clockport fancy 3d model added
    [WM1200.kicad_pcb]
2020-03-05 Board pcb updated
    [WM1200.kicad_pcb, buffers_addr.sch, buffers_data.sch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]
2020-03-05 clockport removed from ES1 pcb design (maybe another time)
    [WM1200.kicad_pcb, WM1200.sch]
2020-03-05 SCH comments updated
    [FPGA_devboard.sch, WM1200.sch, audio.sch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]
2020-03-05 Ground plane added
    [WM1200.kicad_pcb]
2020-03-05 Sync work
    [WM1200.kicad_pcb]
2020-03-05 some work on hdmi part
    [WM1200.kicad_pcb, buffers_system_zorroii.sch]
2020-03-05 some more work done
    [WM1200.kicad_pcb, buffers_addr.sch, buffers_data.sch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]
2020-03-06 Buffers power scheme rework in progress, re-annotate board
    [FPGA_devboard.sch, WM1200.kicad_pcb, buffers_addr.sch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]
2020-03-06 Unused buffer io are now grounded via testpads
    [WM1200.kicad_pcb, buffers_system_zorroii.sch]
2020-03-06 Some work done, sync
    [WM1200.kicad_pcb, buffers_addr.sch, buffers_data.sch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]
2020-03-06 still working
    [WM1200.kicad_pcb, power.sch]
2020-03-08 some dirty routing
    [FPGA_devboard.sch, WM1200.kicad_pcb, buffers_addr.sch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]
2020-03-08 time to stop for today
    [FPGA_devboard.sch, WM1200.kicad_pcb, open_collector.sch]
2020-03-09 wire length aligns
    [FPGA_devboard.sch, WM1200.kicad_pcb]
2020-03-11 Some more work done
    I'm too lazy to think about commit messages in my pet project, really
    [FPGA_devboard.sch, WM1200.kicad_pcb, hdmi.sch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]
2020-03-11 bigger vias, fixing DRC issues
    [FPGA_devboard.sch, WM1200.kicad_pcb]
2020-03-12 DRC passed
    [WM1200.kicad_pcb]
2020-03-12 rerouted one trace, sync
    [WM1200.kicad_pcb]
2020-03-16 ready for production
    [FPGA_devboard.sch, WM1200.kicad_pcb, WM1200.sch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]
2020-03-16 board updated - factory DRC checking in progress
    [FPGA_devboard.sch, WM1200.kicad_pcb, audio.sch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]
2020-03-16 factory DRC passed
    [WM1200.kicad_pcb, open_collector.sch, power.sch]
2020-03-16 gerber files uploaded
    [WM1200-B_Cu.gbl, WM1200-B_Mask.gbs, WM1200-B_Paste.gbp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]
2020-03-17 remind myself to connect CPUCLK to clock-capable pin in the future board revisions
    [FPGA_devboard.sch]
2020-10-28 I'm too lazy to create a normal BOM. so here's an auto-generated one
